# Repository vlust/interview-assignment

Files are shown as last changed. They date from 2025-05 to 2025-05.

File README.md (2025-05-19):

# Interview Assignment

The hardest part of this project was making design decisions. If the goal were simply to solve the scenario described in the assignment introduction, a basic multimeter would have sufficed. So with little to no design, monetary, or other constraints, I decided to base my choices on how interesting I found the solutions, of course only when there was no clear direction provided in the task.

## Task 1

The 4–20 mA interface was not specified, so I assumed a sensor with an integrated transmitter and chose a 100 Ω shunt resistor, expecting a 0.4 V to 2 V voltage output (if the transmitter in the sensor could not provide a 2V voltage for example the shunt resistor would have to be changed). If the sensor were just a passive component, a transmitter circuit would be required.

I attempted to build the circuit using components I had available to make the process more interesting. The result is this schematic: [CurrentSensorUSB\_prototype.pdf](hardware/CurrentSensorUSB_prototype/CurrentSensorUSB_prototype.pdf). I didn’t have any components to achieve galvanic isolation between the MCU and the current measurement, but I was able to use the circuit to test the Python data acquisition software. I wrote the firmware in Rust because I had never tried embedded Rust before [README.md](firmware/README.md).

The prototype circuit didn’t fully meet the requirements outlined in the task, so I created another schematic: [CurrentSensorUSB.pdf](hardware/CurrentSensorUSB/CurrentSensorUSB.pdf), along with a BOM: [CurrentSensorUSB.csv](hardware/CurrentSensorUSB/CurrentSensorUSB.csv). A more detailed explanation of the component choices can be found here: [README.md](hardware/CurrentSensorUSB/README.md). I couldn’t write the firmware for this circuit because I didn’t have the hardware or toolchain to test it.

## Task 2

The `software` folder contains a Python project with a CLI tool that can acquire a data stream over serial and generate a report based on the acquired data. An example report generated using the prototype board can be found here: [report.pdf](software/data/report_20250518_223138.pdf). More information on this task can be found in the README in the software directory: [README.md](software/README.md).

## Task 3

### 1. Procurement and Documentation

* **Bill of Materials (BOM):**

  * List each component’s reference designator, manufacturer part number, quantity, package, and tolerance. ([BOM](hardware/CurrentSensorUSB/CurrentSensorUSB.csv))

* **Supplier Selection:**

  * Order from authorized distributors (e.g., Digi‑Key, Mouser).
  * Verify lead times (aim for < 8 weeks) and minimum reel‑quantities match production volume.

* **Files for Suppliers:**

  * **PCB Fabricator:** Gerber RS‑274X package (copper, mask, silkscreen, drill), board outline (DXF/PDF), impedance spec (90 Ω differential for USB lanes).
  * **Assembly House:** BOM, pick‑and‑place (centroid) file, paste‑mask Gerbers, assembly drawing PDFs.

---

### 2. Manufacturing Steps

1. **PCB Fabrication (DFM Review)**

   * Ensure trace/space, via sizes, and 2.5 mm isolation clearance meet standards.
   * Four‑layer stack‑up (2 signal, 2 power/ground) for stable analog and controlled‑impedance USB. (Optional: separate isolation layers, though I didn’t have time to finish that layout, and it wasn’t required in the task description.)

2. **Assembly (PCBA)**

   * Provide a laser‑cut stencil for solder paste.
   * Match the reflow profile to the most temperature‑sensitive IC.
   * Perform post‑reflow AOI to catch solder defects. Since no QFN parts are used, X‑ray inspection is not necessary.

3. **Firmware Provisioning**

   * Use a simple SWD/JTAG fixture and ST‑Link (or equivalent) to program each MCU with the final Rust firmware binary.
   * It may be advisable to build a small dev board with a USB bootloader and debugger for a better firmware development experience (the current design has only SWD headers).

---

### 3. Testing and Calibration

* **Incoming Inspection (IQC):**

  * Sample critical parts (shunt resistor, op‑amp, isolator) to verify values and functionality.

* **In‑Process Checks:**

  * **Bare‑Board Test:** Use flying‑probe or ICT to catch opens/shorts.
  * **Power‑Up Smoke Test:** Limit current to \~100 mA, verify no excessive draw or heating.

* **End‑of‑Line Functional Test (FCT):**

  1. **USB Enumeration:** Ensure the board appears as a CDC/Serial device; verify VID/PID and basic loopback.

  2. **Current‑Loop Accuracy:**

     * Use a 4–20 mA precision source (≤ 0.01 % accuracy) to apply five setpoints (4, 8, 12, 16, 20 mA).
     * Read back ADC counts via USB; compute offset and gain error.
     * Adapt the Python data acquisition tool to create automatic reports (see [report\_20250518\_223138.pdf](software/data/report_20250518_223138.pdf)).
     * The MCU should communicate the firmware version and serial number on startup to build that identifier into the report.

  3. **Calibration:**

     * Adjust offset (at 4 mA) and gain (at 20 mA) by programming compensation coefficients into flash. (Trim resistors could also be added to the board for calibration.)
     * Verify mid‑point (e.g., 12 mA) to confirm linearity within tolerance.

  4. **Isolation Test:**

     * Perform a hipot test between the USB side and the sensor side to confirm isolation and leakage requirements.

* **Traceability:**

  * Assign each board a serial number; record calibration data (offset/gain) and test results in a simple CSV or database, with links to the generated reports.

---

### 4. Required Equipment & Files Summary

| **Category** | **Files/Supplies** | **Equipment** |
| --- | --- | --- |
| **PCB Fab** | Gerbers, drill file, board outline (DXF/PDF), impedance spec | — |
| **PCB Assembly** | BOM (incl. alternates), pick‑and‑place, paste‑mask Gerbers | Pick‑and‑place machine, reflow oven, AOI |
| **Firmware/Programming** | Final Rust `.bin`/`.hex`, programming script, README | SWD/JTAG programmer (ST‑Link), PC |
| **Functional Testing** | Test‑fixture drawing, FCT script (Python), calibration doc | 4–20 mA precision source (e.g., Keithley), 6½‑digit DMM, oscilloscope, USB protocol analyzer, hipot tester |

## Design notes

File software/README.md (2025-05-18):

# Current Sensor Reader

`current-sensor-reader` is a Python toolchain for acquiring serial data from a custom current sensor, plotting the measurements, and generating a LaTeX report.

## Features
- Read real-time current measurements over serial (supports physical COM ports and `loop://` emulator).
- Save raw data to a timestamped CSV file in an output directory.
- Plot measurements with Matplotlib.
- Generate a PDF report via LaTeX template (requires a LaTeX installation).

## Prerequisites
- [uv](https://docs.astral.sh/uv/getting-started/installation)
- A LaTeX distribution (e.g. TeX Live, MiKTeX) on your PATH to compile reports

## Installation

1. Clone the repository:
   ```bash
   git clone https://github.com/vlust/interview-assignment.git && cd interview-assignment/software
   ```

## Usage

Run the main CLI script to acquire data, generate a plot, and build a report:

```bash
uv run acquire_sonsor_data.py \
  --port COM3           # not needed for --test
  --baud 9600           # serial baud rate
  --duration 60         # acquisition duration (seconds)
  --outdir ./output     # directory to save CSV, plot, and report
  [--test]              # start built-in emulator (only valid with loop://)
```

### Example
```bash
uv run acquire_sonsor_data.py --test --duration 10 --outdir ./results
```
- Creates `results/data_YYYYMMDD_HHMMSS.csv` containing timestamp/value columns.
- Generates `results/plot_YYYYMMDD_HHMMSS.png`
- Writes `results/report_YYYYMMDD_HHMMSS.tex` and compiles to PDF using the LaTeX template in the project root.

## License
[MIT](LICENSE)

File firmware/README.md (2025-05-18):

firmware
========

Rust project for the _Arduino Nano_.

## Build Instructions
1. Install prerequisites as described in the [`avr-hal` README] (`avr-gcc`, `avr-libc`, `avrdude`, [`ravedude`]).

2. Run `cargo build` to build the firmware.

3. Run `cargo run` to flash the firmware to a connected board.  If `ravedude`
   fails to detect your board, check its documentation at
   <https://crates.io/crates/ravedude>.

4. `ravedude` will open a console session after flashing where you can interact
   with the UART console of your board.

[`avr-hal` README]: https://github.com/Rahix/avr-hal#readme
[`ravedude`]: https://crates.io/crates/ravedude

## License
Licensed under either of

 - Apache License, Version 2.0
   ([LICENSE-APACHE](LICENSE-APACHE) or <http://www.apache.org/licenses/LICENSE-2.0>)
 - MIT license
   ([LICENSE-MIT](LICENSE-MIT) or <http://opensource.org/licenses/MIT>)

at your option.

## Contribution
Unless you explicitly state otherwise, any contribution intentionally submitted
for inclusion in the work by you, as defined in the Apache-2.0 license, shall
be dual licensed as above, without any additional terms or conditions.

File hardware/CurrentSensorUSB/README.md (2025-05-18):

# Design Considerations

## 1. Microcontroller (U1: ATSAMD21E18A‑A)

  * **Built‑in USB Full‑Speed interface** simplifies serial‑over‑USB implementation.
  * Proven ecosystem and popularity
  * E‑Series package (smallest) has more than enough GPIO and ADC channels for this project.

---

## 2. Precision ADC (U3: ADS1113IDGS)

  * **16‑bit resolution** yields better than 10 µA resolution over the 4–20 mA span by adjusting the PGA settings.
  * Single‑ended input with onboard reference minimizes external parts.
  * I²C interface maps cleanly to the SAMD21 peripheral.

---

## 3. Digital Isolator (U5: ADuM1250)

  * Provides **2.5 kV galvanic isolation** on I2C lines.
  * Ensures USB‑side ground is fully isolated from the analog front end.

---

## 4. DC–DC Converter (PS1: MEE1S0503SC)

  * Generates an **isolated 3.3 V rail** from USB 5 V for the sensor‑side analog domain.
  * 150 mW output rating covers the ADS1113 + op‑amps + isolator.

---

## 5. Shunt Resistor (R2: 100 Ω LVK12)

  * Converts 4–20 mA into 0.4–2.0 V (with gain stage, maps to 0.2–1.0 V for the ADS1113).
  * **0.1 % tolerance** keeps measurement error < ±1 µA.

---

## 6. Voltage Regulator (U2: MCP1703A‑3302)

  * **3.3 V LDO** for the SAMD21 from the USB 5 V rail.

---

## 7. ESD Protection (D1: PRTR5V0U2X)

  * I wanted to incoorperate an example for circuit protection but without having a clear safety bufget i decided to keep it minimal.

---

## 8. 32.768 kHz Crystal (Y1)

  * Provides a **precision RTC clock** for timestamping the serial out.
  * Matched load capacitance (6.8 pF) aligns with the SAMD21’s XOSC32K requirements.

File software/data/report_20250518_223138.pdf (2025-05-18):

Data Acquisition Report | 2025-05-18 22:32:38

# Data Acquisition Report

Department / Institution

Script: | acquire sonsor data.py
Port: | COM3
Baud rate: | 9600 bit s⁻¹
Test mode: | False
Duration: | 60.0 s
Git remote: | https://github.com/vlust/interview-assignment.git
Git commit: | 58ec9bef8209fa7d6595115be404b474721c9a91
Timestamp: | 2025-05-18 22:32:38

## 1. Introduction

A loopback test was performed to validate the data-acquisition script and communication pipeline. By sending a known ramp signal over a virtual serial interface, we verify integrity before deploying to actual hardware.

## 2. Methods

Interface: Virtual serial port (loop://) at 9600 bit s⁻¹
| Duration: 3 s
| Logging: Timestamped <timestamp, value> entries to CSV; buffered I/O to minimize latency.

## 3. Results

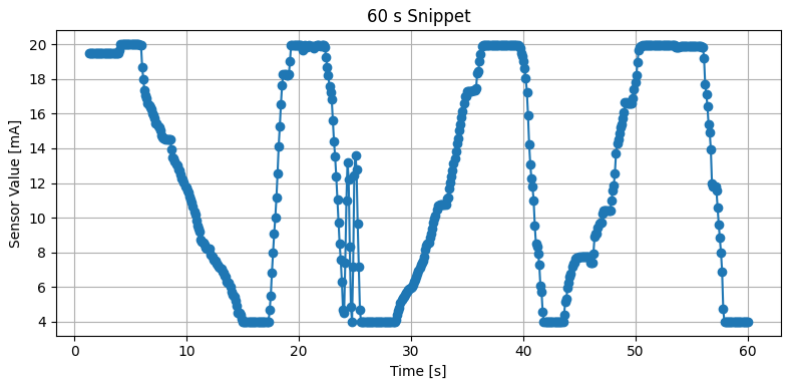
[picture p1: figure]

Figure 1: Acquired ramp signal over 60.0 s via loopback.

1

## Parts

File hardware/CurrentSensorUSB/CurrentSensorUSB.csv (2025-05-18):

Reference | Qty | Value | DNP | Exclude from BOM | Exclude from Board | Footprint | Datasheet/Partnumber
C1,C2 | 2 | 1 μF Ceramic |  |  |  | Capacitor_SMD:C_0603_1608Metric | ~
C3 | 1 | 0.1 μF |  |  |  | Capacitor_SMD:C_0603_1608Metric | ~
C4 | 1 | C |  |  |  | Capacitor_SMD:C_0603_1608Metric | ~
C5,C6 | 2 | 6.8pF |  |  |  | Capacitor_SMD:C_0603_1608Metric | ~
C7 | 1 | 1 μF |  |  |  | Capacitor_SMD:C_0603_1608Metric | ~
D1 | 1 | PRTR5V0U2X |  |  |  | Package_TO_SOT_SMD:SOT-143 | https://assets.nexperia.com/documents/data-sheet/PRTR5V0U2X.pdf
J1 | 1 | TC2030 |  | Excluded from BOM |  | Connector:Tag-Connect_TC2030-IDC-NL_2x03_P1.27mm_Vertical | https://www.tag-connect.com/wp-content/uploads/bsk-pdf-manager/2019/12/TC2030-IDC-NL-Datasheet-Rev-B.pdf
J2 | 1 | Screw_Terminal_01x02 |  |  |  | TerminalBlock_Phoenix:TerminalBlock_Phoenix_MKDS-1,5-2_1x02_P5.00mm_Horizontal | ~
P1 | 1 | USB_C_Plug_USB2.0 |  |  |  | Connector_USB:USB_C_Plug_Molex_105444 | https://www.usb.org/sites/default/files/documents/usb_type-c.zip
PS1 | 1 | MEE1S0503SC |  |  |  | Converter_DCDC:Converter_DCDC_Murata_MEE1SxxxxSC_THT | https://power.murata.com/pub/data/power/ncl/kdc_mee1.pdf
R1 | 1 | 5.1K |  |  |  | Resistor_SMD:R_0603_1608Metric | ~
R2 | 1 | R_Shunt 100 |  |  |  | Resistor_SMD:R_Shunt_Ohmite_LVK12 | LVK12R100FER
R3,R4,R5,R6 | 4 | 4.7 kΩ |  |  |  | Resistor_SMD:R_0603_1608Metric | ~
R7 | 1 | R_F 1 kΩ |  |  |  | Resistor_SMD:R_0603_1608Metric | ~
SW1 | 1 | SW_Push |  |  |  | Button_Switch_SMD:SW_MEC_5GSH9 | 5GSH935
U1 | 1 | ATSAMD21E18A-A |  |  |  | Package_QFP:TQFP-32_7x7mm_P0.8mm | http://ww1.microchip.com/downloads/en/DeviceDoc/SAM_D21_DA1_Family_Data%20Sheet_DS40001882E.pdf
U2 | 1 | MCP1703Ax-330xxDB |  |  |  | Package_TO_SOT_SMD:SOT-223-3_TabPin2 | http://ww1.microchip.com/downloads/en/DeviceDoc/20005122B.pdf
U3 | 1 | ADS1113IDGS |  |  |  | Package_SO:TSSOP-10_3x3mm_P0.5mm | http://www.ti.com/lit/ds/symlink/ads1113.pdf
U5 | 1 | ADuM1250 |  |  |  | Package_SO:SOIC-8_3.9x4.9mm_P1.27mm | https://www.analog.com/media/en/technical-documentation/data-sheets/ADuM1250_1251.pdf
Y1 | 1 | 32.768kHz, 7pF |  |  |  | Crystal:Crystal_SMD_0603-4Pin_6.0x3.5mm | ECS-.327-7-34Q-TR

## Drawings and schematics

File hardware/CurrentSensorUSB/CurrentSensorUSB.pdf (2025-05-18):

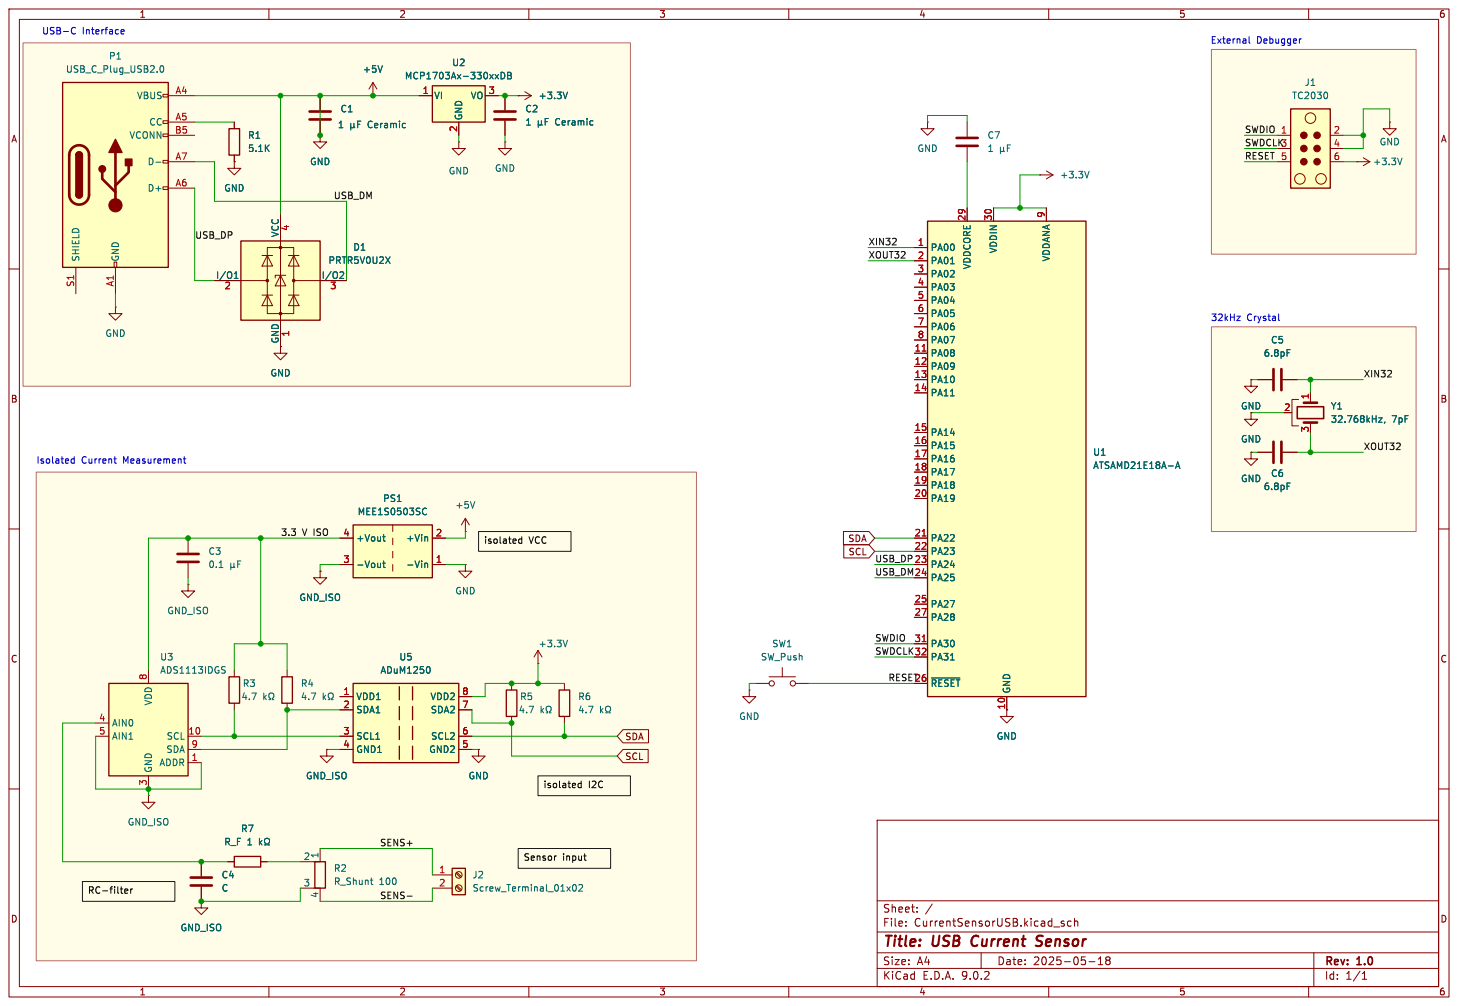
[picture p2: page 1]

1 þÿ¼FCeramic GND GND

Sensor input RC-filter

Id: 1/1 Title: USB Current Sensor File: CurrentSensorUSB.kicad_sch Sheet: /

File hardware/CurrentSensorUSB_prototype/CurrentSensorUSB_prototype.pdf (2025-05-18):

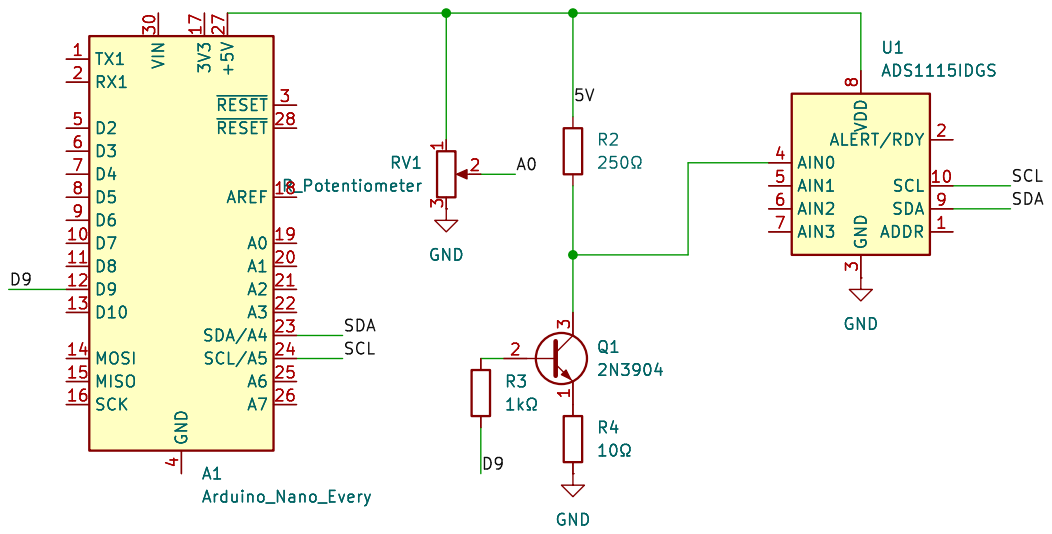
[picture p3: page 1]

3 ALERT/RDY 2 SCL 10 SDA 9 ADDR 1 U1ADS1115IDGS R4

3 ALERT/RDY 2 SCL 10 SDA 9 ADDR 1 RV1 R_Potentiometer 1 3

Id: 1/1 Title: Prototype Current Sensing

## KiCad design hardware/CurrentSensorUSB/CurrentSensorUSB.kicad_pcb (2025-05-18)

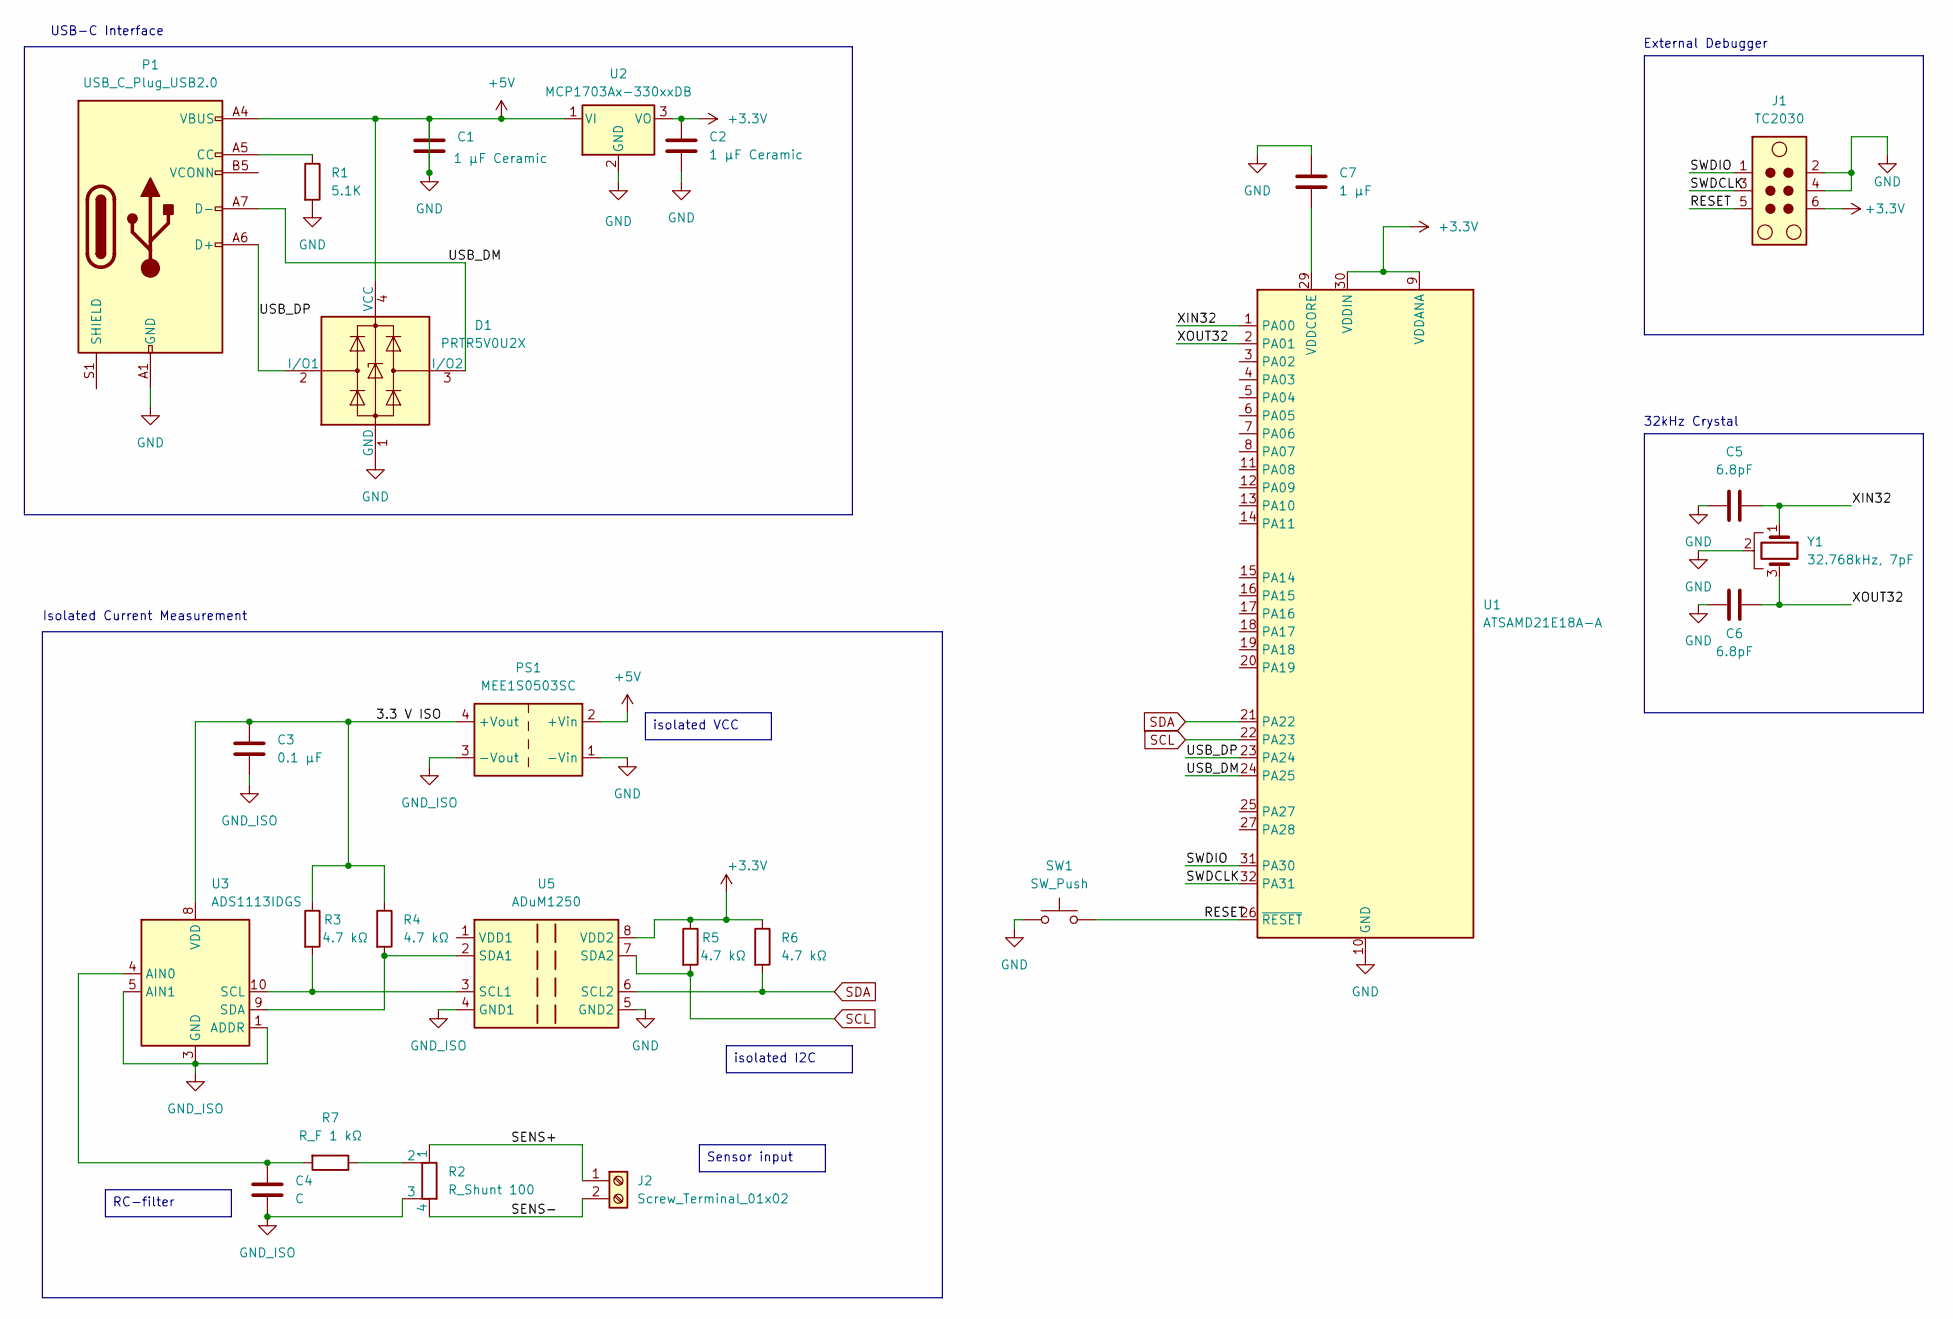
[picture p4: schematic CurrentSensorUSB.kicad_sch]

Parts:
C1, C2: 1 μF Ceramic; C_0603_1608Metric
C3: 0.1 μF; C_0603_1608Metric
C4: C; C_0603_1608Metric
C5, C6: 6.8pF; C_0603_1608Metric
C7: 1 μF; C_0603_1608Metric
D1: PRTR5V0U2X; SOT-143
J1: TC2030; Tag-Connect_TC2030-IDC-NL_2x03_P1.27mm_Vertical
J2: Screw_Terminal_01x02; TerminalBlock_Phoenix_MKDS-1,5-2_1x02_P5.00mm_Horizontal
P1: USB_C_Plug_USB2.0; USB_C_Plug_Molex_105444
PS1: MEE1S0503SC; Converter_DCDC_Murata_MEE1SxxxxSC_THT
R1: 5.1K; R_0603_1608Metric
R2: R_Shunt 100; R_Shunt_Ohmite_LVK12
R3, R4, R5, R6: 4.7 kΩ; R_0603_1608Metric
R7: R_F 1 kΩ; R_0603_1608Metric
SW1: SW_Push; SW_MEC_5GSH9
U1: ATSAMD21E18A-A; TQFP-32_7x7mm_P0.8mm
U2: MCP1703Ax-330xxDB; SOT-223-3_TabPin2
U3: ADS1113IDGS; TSSOP-10_3x3mm_P0.5mm
U5: ADuM1250; SOIC-8_3.9x4.9mm_P1.27mm
Y1: 32.768kHz, 7pF; Crystal_SMD_0603-4Pin_6.0x3.5mm

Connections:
+3.3V: C2.1, J1.6, R5.1, R6.1, U1.9 (VDDANA), U1.30 (VDDIN), U2.3 (VO), U5.8 (VDD2)
+5V: C1.1, C1.2, C2.2, C5.2, C6.2, C7.1, D1.1 (GND), D1.4 (VCC), J1.2, J1.4, P1.A1 (GND), P1.A4 (VBUS), P1.A9 (VBUS), P1.A12 (GND), P1.B1 (GND), P1.B4 (VBUS), P1.B9 (VBUS), P1.B12 (GND), PS1.1 (-Vin), PS1.2 (+Vin), R1.2, SW1.1, U1.10 (GND), U1.28 (GND), U2.1 (VI), U2.2 (GND), U5.5 (GND2), Y1.2
/3.3 V ISO: C3.1, PS1.4 (+Vout), R3.1, R4.1, U3.8 (VDD)
/RESET: J1.5, SW1.2, U1.26 (~RESET)
/SENS+: J2.1, R2.1
/SENS-: J2.2, R2.4
/SWDCLK: J1.3, U1.32 (PA31)
/SWDIO: J1.1, U1.31 (PA30)
/USB_DM: D1.3 (I/O2), P1.A7 (D-), U1.24 (PA25)
/USB_DP: D1.2 (I/O1), P1.A6 (D+), U1.23 (PA24)
/XIN32: C5.1, U1.1 (PA00), Y1.1
/XOUT32: C6.1, U1.2 (PA01), Y1.3
GND_ISO: C3.2, C4.2, PS1.3 (-Vout), R2.3, U3.1 (ADDR), U3.3 (GND), U3.5 (AIN1), U5.4 (GND1)
unnamed: P1.A5 (CC), R1.1
unnamed: R2.2, R7.1
unnamed: C7.2, U1.29 (VDDCORE)
unnamed: C4.1, R7.2, U3.4 (AIN0)
unnamed: R3.2, U3.10 (SCL), U5.3 (SCL1)
unnamed: R4.2, U3.9 (SDA), U5.2 (SDA1)
SCL: R5.2, U1.22 (PA23), U5.7 (SDA2)
SDA: R6.2, U1.21 (PA22), U5.6 (SCL2)

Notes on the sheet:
32kHz Crystal
USB-C Interface
Isolated Current Measurement
External Debugger
isolated VCC
isolated I2C
Sensor input
RC-filter

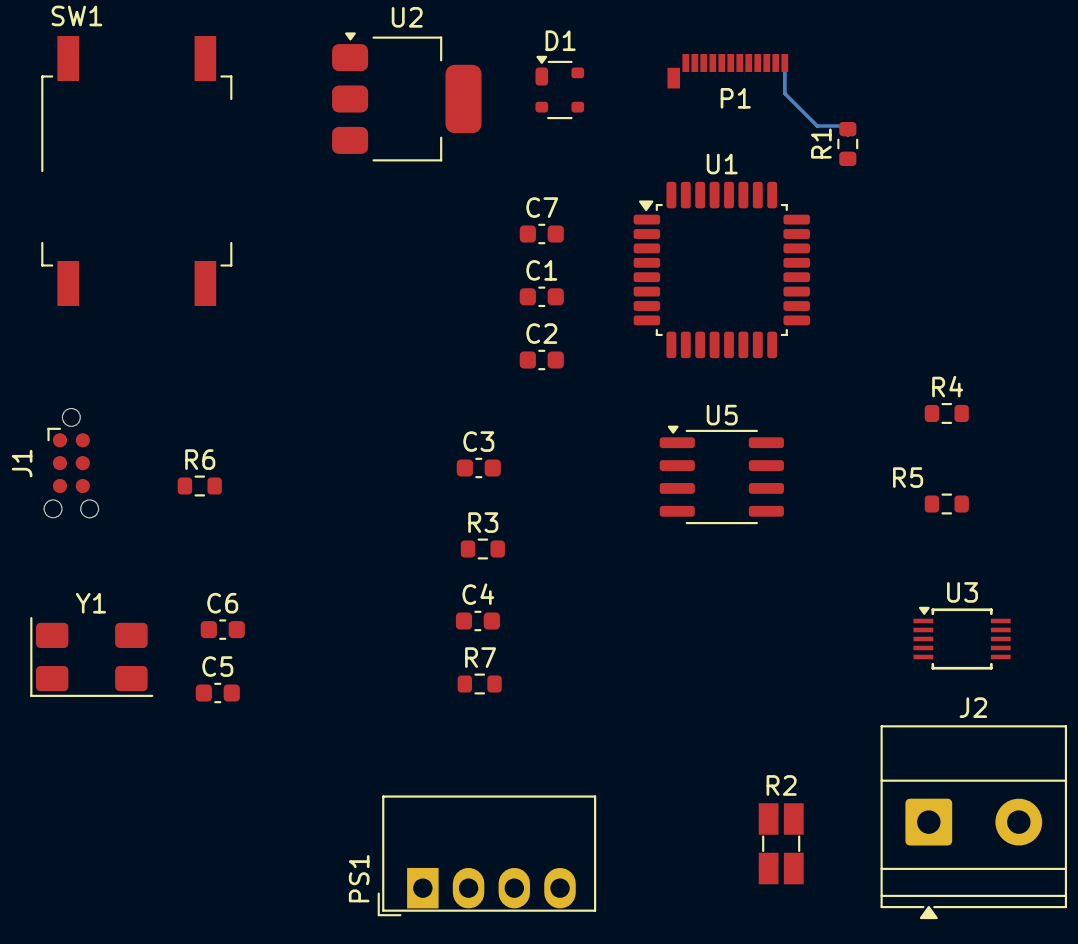
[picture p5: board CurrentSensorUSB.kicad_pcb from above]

Board: 2 copper layers, 25 parts (0 on the bottom side), 21 nets.

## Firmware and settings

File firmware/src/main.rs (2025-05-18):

#![no_std]
#![no_main]

use panic_halt as _;

use arduino_hal::pins;


// ADS1x1x driver (v0.3.0). We only need `Ads1x1x::new_ads1115`, `FullScaleRange`, `DataRate16Bit`, and `TargetAddr`.
use ads1x1x::{
    Ads1x1x,
    channel::DifferentialA0A1,
    DataRate16Bit,
    FullScaleRange,
    TargetAddr,
};
#[arduino_hal::entry]
fn main() -> ! {
    let dp = arduino_hal::Peripherals::take().unwrap();

    let mut pins = pins!(dp);

    let mut serial = arduino_hal::default_serial!(dp, pins, 9_600);

    let mut led = pins.d13.into_output();


    let sda = pins.a4.into_pull_up_input();
    let scl = pins.a5.into_pull_up_input();


    let i2c = arduino_hal::I2c::new(dp.TWI, sda, scl, 100_000);


    let mut adc = Ads1x1x::new_ads1115(i2c, TargetAddr::Gnd);

    adc.set_full_scale_range(FullScaleRange::Within4_096V).unwrap();


    adc.set_data_rate(DataRate16Bit::Sps128).unwrap();

    const SHUNT_RESISTANCE_OHM: f32 = 100.0;

    arduino_hal::delay_ms(100);

    loop {


        let raw: i16 = adc.read(DifferentialA0A1).unwrap();


        let volts: f32 = (raw as f32) * 4.096_f32 / 32_768.0_f32;

        let current_a: f32 = volts / SHUNT_RESISTANCE_OHM;
        let current_ma: f32 = current_a * 1_000.0_f32;


        let centi_milliamp: i16 = (current_ma * 100.0_f32) as i16; // e.g. 1234 for 12.34 mA
        let whole: i16 = centi_milliamp / 100;                     // 12
        let fract: i16 = (centi_milliamp.abs() % 100) as i16;      // 34

        // ufmt::uwrite!(&mut serial, "I: ").unwrap();
        // ufmt::uwrite!(&mut serial, "{}", whole).unwrap();
        // ufmt::uwrite!(&mut serial, ".").unwrap();
        if fract < 10 {
            ufmt::uwrite!(&mut serial, "0").unwrap();
        }
        // ufmt::uwrite!(&mut serial, "{}", fract).unwrap();
        // ufmt::uwrite!(&mut serial, " mA\r\n").unwrap();

        // —————————————————————————————————————————————————————————————————————
        if current_ma < 4.0_f32 || current_ma > 20.0_f32 {
            led.toggle();
        } else {
            led.set_low();
        }


        arduino_hal::delay_ms(200);
    }
}

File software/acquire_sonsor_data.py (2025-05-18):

#!/usr/bin/env python3
import argparse
import time
import serial
import os
import datetime
from argparse import Namespace
from pathlib import Path

from lib.data_acquirer import acquire_data
from lib.plotter import plot_data
from lib.report import generate_report


def main() -> None:
    """
    Acquire serial sensor data for a given duration, plot the results, and generate a LaTeX report.
    """
    p = argparse.ArgumentParser(description="Read serial data for a specified duration and plot it")
    p.add_argument(
        "--port",
        default="loop://",
        help="Serial port URL (e.g. loop:// or COM3 or /dev/pts/5)",
    )
    p.add_argument("--baud", type=int, default=9600)
    p.add_argument(
        "--outdir",
        default=".",
        help="Directory to save outputs",
    )
    p.add_argument("--test",    action="store_true", help="Run built-in emulator (loop:// only)")
    p.add_argument("--duration", type=float, default=60.0, help="Duration in seconds to record data")
    args: Namespace = p.parse_args()

    outdir = Path(args.outdir)
    os.makedirs(outdir, exist_ok=True)
    date_str = datetime.datetime.now().strftime("%Y%m%d_%H%M%S")

    ser = serial.serial_for_url(args.port, baudrate=args.baud, timeout=1)
    # start emulator if requested (only works on loop://)
    if args.test and args.port.startswith("loop://"):
        from lib.emulator import start_emulator
        start_emulator(ser, args.duration)
    print(f"[cli] Listening on {args.port} for {args.duration} seconds...")

    # Acquire data
    timestamps, values = acquire_data(ser, args.duration, outdir)
    ser.close()
    print("[cli] Done acquiring. Generating plot...")

    # Plot data
    plot_path = plot_data(timestamps, values, args.duration, outdir, date_str)

    # Generate LaTeX report
    report_filename = f"report_{date_str}.tex"
    report_path = os.path.join(outdir, report_filename)
    generate_report(vars(args), {'timestamps': timestamps, 'values': values}, __file__, plot_path, report_path)


if __name__ == "__main__":
    main()

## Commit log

2025-05-18 added prototype schematics
    [CurrentSensorUSB_prototype.kicad_pcb, CurrentSensorUSB_prototype.kicad_sch]
2025-05-18 added schematics for final version
    [CurrentSensorUSB.kicad_pcb, CurrentSensorUSB.kicad_sch]
2025-05-18 not saved
    [CurrentSensorUSB.kicad_pcb, CurrentSensorUSB.kicad_sch]
2025-05-18 changes in schematic
    [CurrentSensorUSB.kicad_sch]
2025-05-18 example csv
    [data_20250518_223138.csv]
2025-05-18 bom edited
    [CurrentSensorUSB.csv]
2025-05-18 aded runst firmware for prototype circuit
2025-05-18 pdf schematics
2025-05-18 pcb layout attempt
    [CurrentSensorUSB.kicad_pcb]
2025-05-18 moved report template to correct position
    [report.py]
2025-05-18 small changes in the schematics pdf
2025-05-18 forgot to save schmatic
    [CurrentSensorUSB.kicad_sch]
